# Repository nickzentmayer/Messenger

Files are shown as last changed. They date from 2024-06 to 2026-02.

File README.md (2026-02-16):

# Long Range Messenger Project

This is a repository of hardware and software for a SX1262 radio based messageing device I made. This device supports a messaging protocol named Hermes that I created with insperation from protocols like TCP. This messenger runs on an ESP32-S3 using the Arduino framework. All code is built and compiled using Platformio. All hardware is managed through heavy use of FreeRTOS tasks. This allows for easy programming and ensures all hardware is utilized in a timely manner.

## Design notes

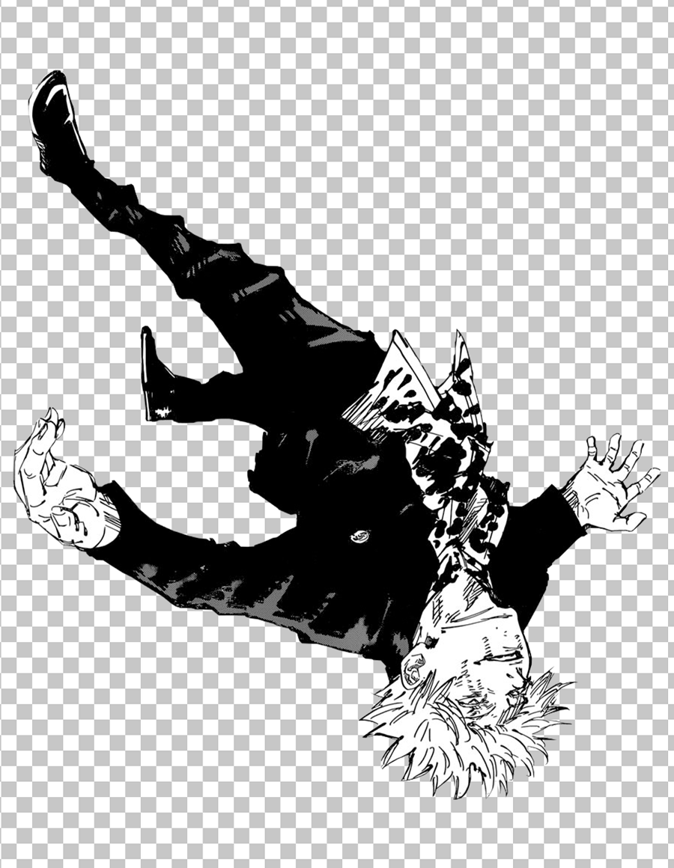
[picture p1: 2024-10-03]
pcb/messenger/gojo.png

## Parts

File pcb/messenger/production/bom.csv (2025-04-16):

Designator | Footprint | Quantity | Value | LCSC Part #
ATGM336H1 | ATGM336H | 1 | ~
BT1 | MSR421R | 1 | MS421R
C1, C2, C21, C29, C3, C32, C6 | 0603 | 7 | 1uF
C10, C17 | 0402 | 2 | 100nF
C11 | 0402 | 1 | 1uF
C12, C18, C20, C31, C7, C8, C9 | 0603 | 7 | 100nF
C13, C14 | 0603 | 2 | 12pF
C15, C16 | 0603 | 2 | 1.8pF
C19, C5 | 0603 | 2 | 10uF
C22 | 0402 | 1 | 47nF
C23 | 0402 | 1 | 470nF
C24 | 0402 | 1 | 47pF
C25, C26 | 0402 | 2 | 1nF
C27 | 0402 | 1 | 39pF
C28 | 0402 | 1 | 10pF
C4 | 0603 | 1 | 10nF
D1 | D_SOD-123 | 1 | MBR0540
D2 | D_MicroMELF | 1 | MCL4148
FL1 | Balun_Johanson_0900FM15K0039 | 1 | 0900FM15K0039
J1 | USB_C_Receptacle_G-Switch_GT-USB-7010ASV | 1 | USB_C_Receptacle_USB2.0_16P
J2 | JST_PH_S2B-PH-SM4-TB_1x02-1MP_P2.00mm_Horizontal | 1 | Battery
J3 | U.FL_Molex_MCRF_73412-0110_Vertical | 1 | Conn_Coaxial
J4 | Hirose_FH12-30S-0.5SH_1x30-1MP_P0.50mm_Horizontal | 1 | Display Connector
J5 | SMA_Amphenol_901-143_Horizontal | 1 | Conn_Coaxial
L2 | 0402 | 1 | 22nH
L3 | 0603 | 1 | 2.4nH
L4, L6 | 0402 | 2 | 47nH
L5 | 0805 | 1 | 15uH
L7 | 0603 | 1 | 2.0nH
Q1_XTAL1 | Crystal_SMD_2016-4Pin_2.0x1.6mm | 1 | 32.0MHz
R1, R21 | 0603 | 2 | 10
R10, R11, R13, R15, R18, R4, R7, R9 | 0603 | 8 | 10k
R12 | 0603 | 1 | 2k
R14, R5 | 0805 | 2 | 2k
R16, R22 | 0402 | 2 | 100R
R17 | 0402 | 1 | 220R
R19, R2, R20, R3 | 0603 | 4 | 5.1k
R6 | 0603 | 1 | 100k
SW1 | vert_button_6mm | 1 | BOOT
SW2 | SW_Push_SPST_NO_Alps_SKRK | 1 | EN
U1, U8, U9 | SOT95P240X105-3N | 3 | DMG3415U-7 | DMG3415U-7
U10 | SOIC-8_5.23x5.23mm_P1.27mm | 1 | W25Q128JVS
U11 | Texas_SWRA117D_2.4GHz_Left | 1 | ~
U12 | BM14B(0.8)-24DS-0.4V(53) | 1 | BBQ10KBD
U13 | RTW24_2P45X2P45 | 1 | TCA8418RTWR
U14 | SOP65P490X110-8N | 1 | 24AA32AF-I_MS | 24AA32AF-I/MS
U16 | BBQ10KBD | 1 | ~
U17 | 21-0168E_T822-3_MXM | 1 | MAX17049G+T10
U18 | SC-70-6_PSM | 1 | PE4259
U19, U6 | XDFN8_1P6X1P2_ONS | 2 | NCP186AMX330TAG
U2 | QFN-56-1EP_7x7mm_P0.4mm_EP4x4mm | 1 | ESP32-S3
U3 | QFN-24-1EP_4x4mm_P0.5mm_EP2.6x2.6mm | 1 | SX1262IMLTRT
U4 | SOT-23-6 | 1 | USBLC6-2SC6
U5 | SOT-23-5 | 1 | MCP73831-2-OT
X1 | Crystal_SMD_Abracon_ABM10-4Pin_2.5x2.0mm | 1 | 40MHz

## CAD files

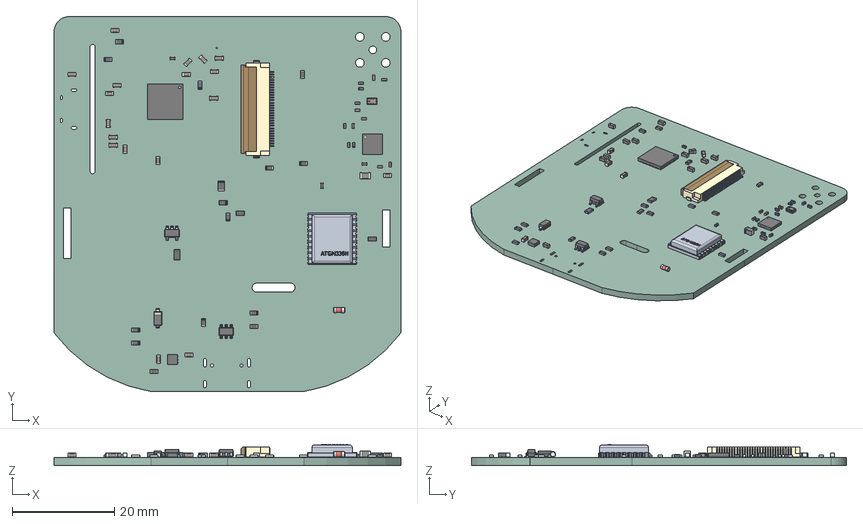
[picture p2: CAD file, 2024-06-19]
pcb/messenger/messenger.step
68.0 x 73.5 x 4.15 mm
C_0402_1005Metric x 11
C_0603_1608Metric x 17
D_SOD_123
R_0603_1608Metric x 16
Hirose_FH12_xxS_0_5SH_Parametric_v0_1
WSON_6_1EP_2x2mm_P065mm_EP1x16mm
R_0805_2012Metric x 2
R_0402_1005Metric x 2
L_0805_2012Metric
L_0402_1005Metric x 3
User Library-ATGM336H
L_0603_1608Metric
CQ assembly
QFN-24-1EP_4x4mm_Pitch0.5mm
D_MicroMELF_Standard
SOT_23_5
4d195fec-b8b3-11ee-a4d2-001e64e93a09
SOT_23_6
_autosave-messenger_PCB

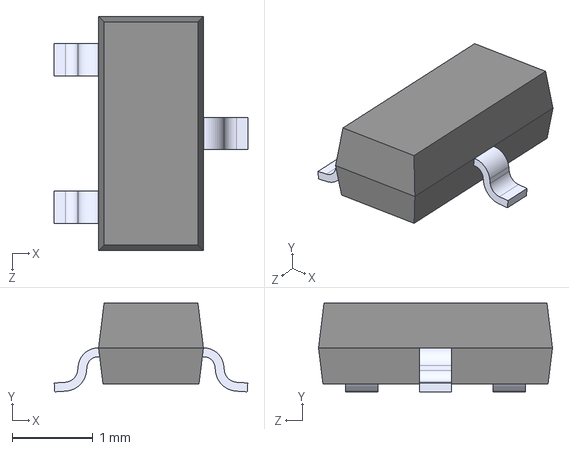
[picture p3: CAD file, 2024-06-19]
pcb/messenger/symbols/DMG3415/DMG3415U-7.step
2.40 x 1.10 x 2.90 mm

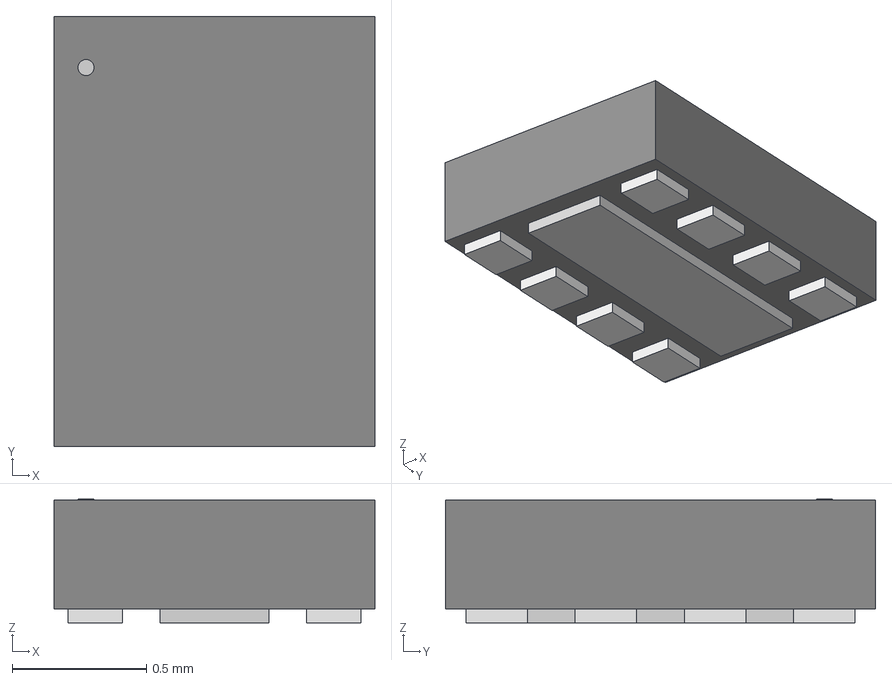
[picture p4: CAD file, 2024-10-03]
pcb/messenger/symbols/NCP186AMX330TAG/XDFN8_1P6X1P2_ONS.step
1.19 x 1.60 x 0.46 mm

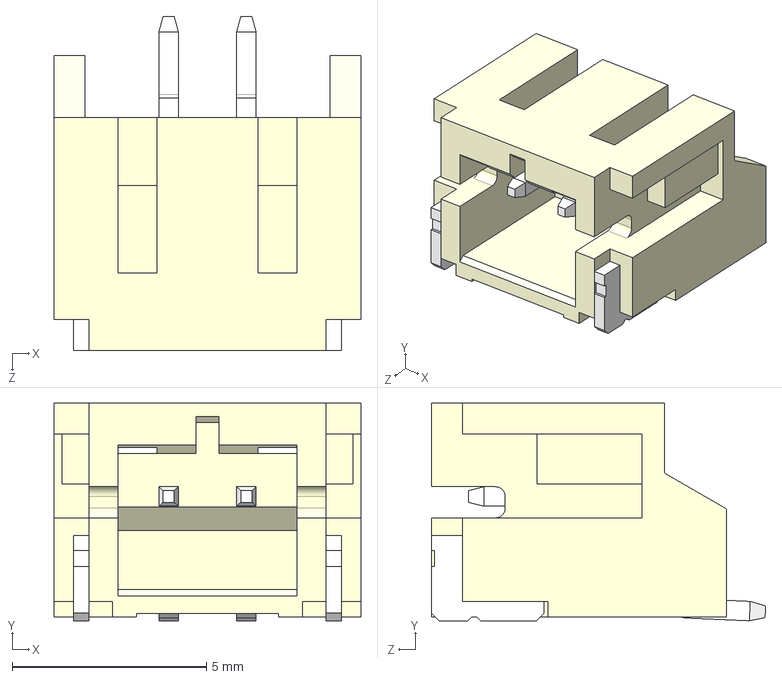
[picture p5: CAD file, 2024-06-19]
pcb/messenger/symbols/S2B-PH-SM4-TB.step
7.90 x 5.60 x 8.60 mm

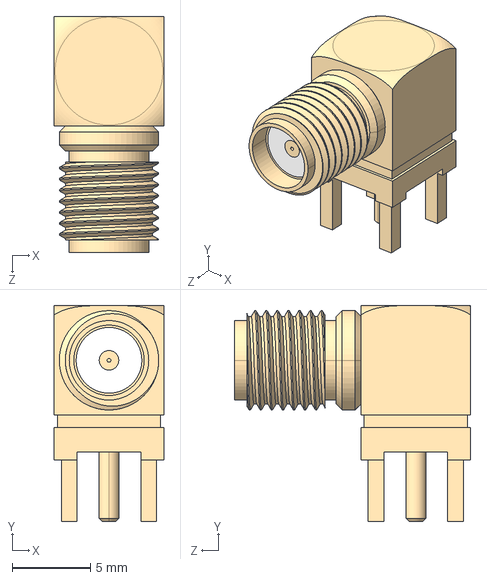
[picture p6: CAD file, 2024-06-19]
pcb/messenger/symbols/901-143.step
7.00 x 13.8 x 15.1 mm

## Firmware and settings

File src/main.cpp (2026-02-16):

#include <Arduino.h>
#include <time.h>
#include "TaskHandler.h"
#include "Keyboard.h"
#include "power.h"
#include "GPS.h"
#include "LoRa.h"
#include "GUI.h"
#include <Preferences.h>


#define CONFIG_SPIRAM_SUPPORT 1

//Task Handling
TaskHandler taskHandler = TaskHandler();
Preferences preferences;


void setup() {
    pinMode(0, INPUT);
    esp_log_set_vprintf(&ramLog);
  if(esp_sleep_get_wakeup_cause() == ESP_SLEEP_WAKEUP_EXT0) {
  int waitTime = 0;
  while(waitTime < 500) {
    if(digitalRead(0)) {
      //esp_sleep_get_ext1_wakeup_status
      esp_sleep_enable_ext0_wakeup(GPIO_NUM_0, LOW);
      esp_deep_sleep_start();
    }
    delay(1);
    waitTime += 1;
  }
}
    #ifdef DEBUG
    //delay(2000);
    esp_log_level_set("*", (esp_log_level_t)4);
    log_d("Running...");
    log_d("HERMES OS %s", "0.0.0");
    Serial.begin(115200);
    #endif
    //time
    configTime(3600*TIMEZONE, DAYSAVETIME*3600, "time.nist.gov", "0.pool.ntp.org", "1.pool.ntp.org");
    //Initialize the File system
        //FS Init
    if (!LittleFS.begin(false)) {
        log_e("Failed to mount file system");
        return;
    } else {
        log_i("File system mounted successfully");
    }
    preferences.begin("Messenger WiFi", true); // Read-only mode

    taskHandler.addSemaphore("i2c");
    taskHandler.addSemaphore("fs");
    taskHandler.addSemaphore("keyboardRW");
    taskHandler.addSemaphore("powerSemaphore");
    taskHandler.addSemaphore("status");
    taskHandler.addSemaphore("gps");
    taskHandler.addSemaphore("radio");
    taskHandler.addSemaphore("WiFi");

    taskHandler.addTask(Power::pwrTask, "Power Task");
    taskHandler.addTask(GUI::guiTask, "GUI Task", 30 * 1024, 2, 1); // GUI task with higher priority
    taskHandler.addTask(Keyboard::keyboardTask, "Keyboard Task", 4096, 1, 0); // Keyboard task handle will be set later
    taskHandler.addTask(GPS::gpsTask, "GPS Task");
    taskHandler.addTask(LoRa::loraTask, "LoRa", 4096, 1, 1);

    // Start the tasks
    taskHandler.startTask("Power Task");
    taskHandler.startTask("GUI Task");
    taskHandler.startTask("Keyboard Task");
    taskHandler.startTask("GPS Task");
    taskHandler.startTask("LoRa");

    //vTaskDelete(NULL);
    WiFi.enableSTA(true);
  }

void loop() {
  //Loop will be used for background tasks like connecting to wifi
  taskHandler.takeSemaphore("WiFi", portMAX_DELAY);
  if(!WiFi.isConnected()) { // If we are not connected to wifi and not already trying to connect
    int n = WiFi.scanNetworks();
    for(int i = 0; i < n; ++i) {
      String ssid = WiFi.SSID(i);
      if(preferences.isKey(ssid.c_str())) {
        String networkInfo;
        networkInfo = preferences.getString(ssid.c_str());
        log_d("Found known network: %s | %s", ssid.c_str(), networkInfo.c_str());
        switch(WiFi.encryptionType(i)) {
          case WIFI_AUTH_OPEN:
            WiFi.begin(ssid.c_str());
            break;
          case WIFI_AUTH_WEP:
          case WIFI_AUTH_WPA_PSK:
          case WIFI_AUTH_WPA2_PSK:
          case WIFI_AUTH_WPA_WPA2_PSK:
            {
              int delimiterIndex = networkInfo.indexOf('|');
              String password = networkInfo.substring(delimiterIndex + 1);
              log_d("Connecting to %s, %s|", ssid.c_str(), password.c_str());
              WiFi.begin(ssid.c_str(), password.c_str());
            }
            break;
          case WIFI_AUTH_ENTERPRISE:
            {
              int delimiter = networkInfo.indexOf('|');
              String username = networkInfo.substring(0, delimiter);
              String password = networkInfo.substring(delimiter + 1);
              log_d("Connecting to %s, %s, %s|", ssid.c_str(), username.c_str(), password.c_str());
              WiFi.begin(ssid.c_str(), WPA2_AUTH_PEAP, username.c_str(), username.c_str(), password.c_str());
            }
            break;
        // case WIFI_AUTH_WPA2_WPA3_ENTERPRISE:
        //     {
        //       int delimiter = networkInfo.indexOf('|');
        //       String username = networkInfo.substring(0, delimiter);
        //       String password = networkInfo.substring(delimiter + 1);
        //       log_d("Connecting to %s, %s, %s|", ssid.c_str(), username.c_str(), password.c_str());
        //       WiFi.begin(ssid.c_str(), WPA2_AUTH_TTLS, username.c_str(), username.c_str(), password.c_str());
        //     }
            break;
          default:
            log_w("Unsupported encryption type for SSID: %s", ssid.c_str());
            break;
        }
        log_d("Connecting to %s", ssid.c_str());
        uint8_t counter = 0;
        while (WiFi.status() != WL_CONNECTED) {
          delay(100);
          counter++;
          if (counter > 70) { // Timeout after 7 seconds
              Serial.println("Connection timed out");
              break;
          }
        }
        if(WiFi.status() == WL_CONNECTED) {
          log_i("Connected to %s, IP: %s", ssid.c_str(), WiFi.localIP().toString().c_str());
          WiFi.setAutoReconnect(true);
          break; // Exit the loop if connected
        } else {
          log_w("Failed to connect to %s", ssid.c_str());
        }
        taskHandler.releaseSemaphore("WiFi");
        delay(3000); // Short delay before trying the next network, allow WiFi app to run if needed
        taskHandler.takeSemaphore("WiFi");
      }
    }
  }
  taskHandler.releaseSemaphore("WiFi");
  delay(30000); // Wait 30 seconds before trying to connect to wifi
}

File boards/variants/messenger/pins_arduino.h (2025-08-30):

#ifndef Pins_Arduino_h
#define Pins_Arduino_h

#include <stdint.h>

#define USB_VID 0x303a
#define USB_PID 0x1001
//You can use the boot button as a normal button
static const uint8_t BUTTON_BOOT = 0;
//Default UART
static const uint8_t TX = 43;
static const uint8_t RX = 44;
//IMU I2C
static const uint8_t SDA = 1;
static const uint8_t SCL = 2;
//SPI - LoRa
static const uint8_t SCK  = 11;
static const uint8_t MISO = 13;
static const uint8_t MOSI = 12;
static const uint8_t SS   = 4;
//LoRa
static const uint8_t LORA_IRQ = 16;
static const uint8_t LORA_RST   = 10;
static const uint8_t LORA_BUSY = 17;
//Power
#define TFT_BACKLIGHT  GPIO_NUM_38
#define LDO_EN  GPIO_NUM_14
#define KEY_BACKLIGHT  GPIO_NUM_21

//Other ESP Stuff
// P1
static const uint8_t PIN_43 = 43;
static const uint8_t PIN_44 = 44;
static const uint8_t PIN_18 = 18;
static const uint8_t PIN_17 = 17;
static const uint8_t PIN_21 = 21;
static const uint8_t PIN_16 = 16;

// P2
static const uint8_t PIN_1  = 1;
static const uint8_t PIN_2  = 2;
static const uint8_t PIN_3  = 3;
static const uint8_t PIN_10 = 10;
static const uint8_t PIN_11 = 11;
static const uint8_t PIN_12 = 12;
static const uint8_t PIN_13 = 13;

// Analog
static const uint8_t A0  = 1;
static const uint8_t A1  = 2;
static const uint8_t A2  = 3;
static const uint8_t A9  = 10;
static const uint8_t A10 = 11;
static const uint8_t A11 = 12;
static const uint8_t A12 = 13;
static const uint8_t A15 = 16;
static const uint8_t A16 = 17;
static const uint8_t A17 = 18;


// Touch
static const uint8_t T1  = 1;
static const uint8_t T2  = 2;
static const uint8_t T3  = 3;
static const uint8_t T10 = 10;
static const uint8_t T11 = 11;
static const uint8_t T12 = 12;
static const uint8_t T13 = 13;

#endif /* Pins_Arduino_h */

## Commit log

2024-06-19 v0.2 pcb
    [901-143.step, DMG3415U-7.step, LoRa.kicad_sch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]
2024-06-19 pcb fixes
    [LoRa.kicad_sch, keyboard.kicad_sch, messenger.kicad_pcb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]
2024-08-28 still dont work
    [LoRa.kicad_sch, bom.csv, designators.csv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]
2024-08-29 Revert "Merge branch 'main' of https://github.com/nickzentmayer/Messenger"
    This reverts commit eeb4965068b8826d2e1f5f35f9c4dc3c3269afb1, reversing
    changes made to 3887d02a7aa76ccf633620887f3bdcfabfaf6fd0.
    [LoRa.kicad_sch, keyboard.kicad_sch, messenger.kicad_pcb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]
2024-09-11 v0.5 (save before chip redesign)
    [LoRa.kicad_sch, keyboard.kicad_sch, messenger.kicad_pcb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]
2024-09-12 halfway to v0.4
    [messenger.kicad_pcb, messenger.kicad_sch]
2024-09-13 Major Revisions v0.4
    New decoupling caps, rerouted for better stability. Changed keyboard connector to help longevity of fpc connector.
    [LoRa.kicad_sch, keyboard.kicad_sch, messenger.kicad_pcb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]
2024-10-03 v0.4.1 Fixed potential issue with crystal circuitry (PLEASE WORK!!!)
    [LoRa.kicad_sch, XDFN8_1P6X1P2_ONS.step, bom.csv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]
2024-10-10 IT WORKS!!!
    [messenger.kicad_pcb]
2025-04-16 Version 1.0.0 | Fully working hardware
    [LoRa.kicad_sch, bom.csv, designators.csv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]
2026-02-16 Added keyboard app, along with other QOL changes
    [messenger.kicad_pcb]
